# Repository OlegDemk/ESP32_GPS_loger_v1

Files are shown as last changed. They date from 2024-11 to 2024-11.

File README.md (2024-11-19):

GPS logger can log in GPS data every 5 seconds into Micro SD card. 

File can be downloaded over Wifi HTTP server or from MicroSD card. 

Log file can be upload on https://earth.google.com for see route. 

All information can be show on HTTP web server, if it turn on.

SMS command:

   command 	   ansvers
   
logON	- 	GPS log Start... Bat: 100%

logoff	- 	GPS log STOP Bat: 100%

point 	- 	49.XXXXXX, 23.XXXXXX Bat: 100%

restart - 	Restarting... Bat: 100%

WiFi commands ??????

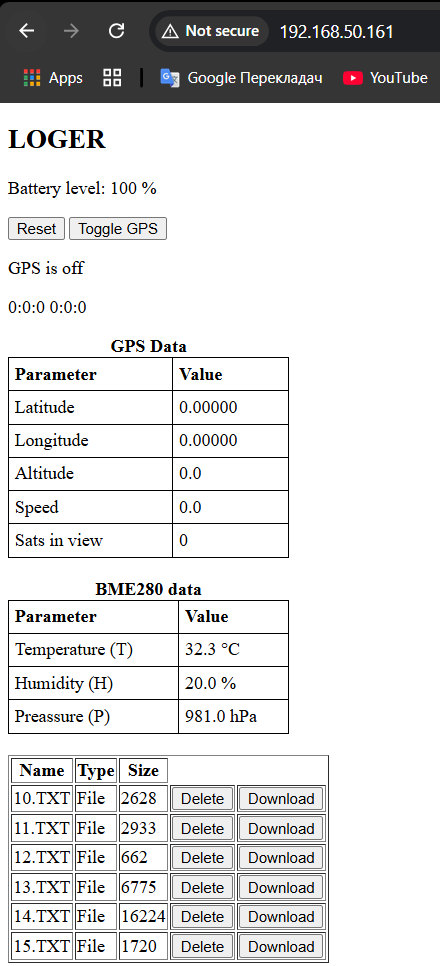
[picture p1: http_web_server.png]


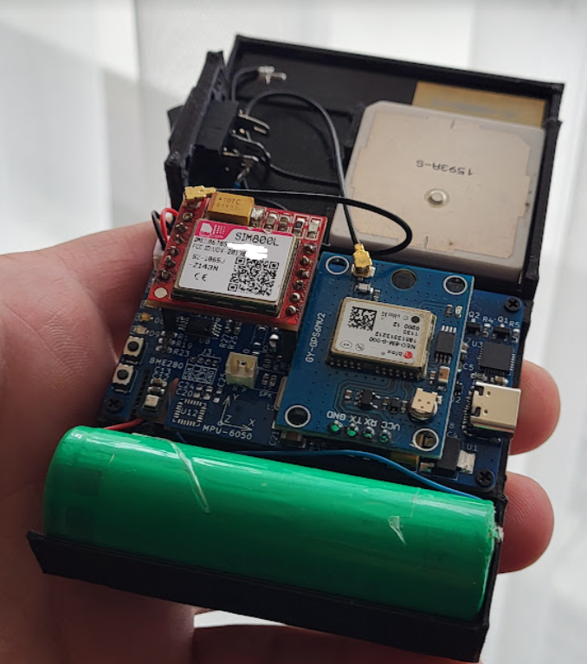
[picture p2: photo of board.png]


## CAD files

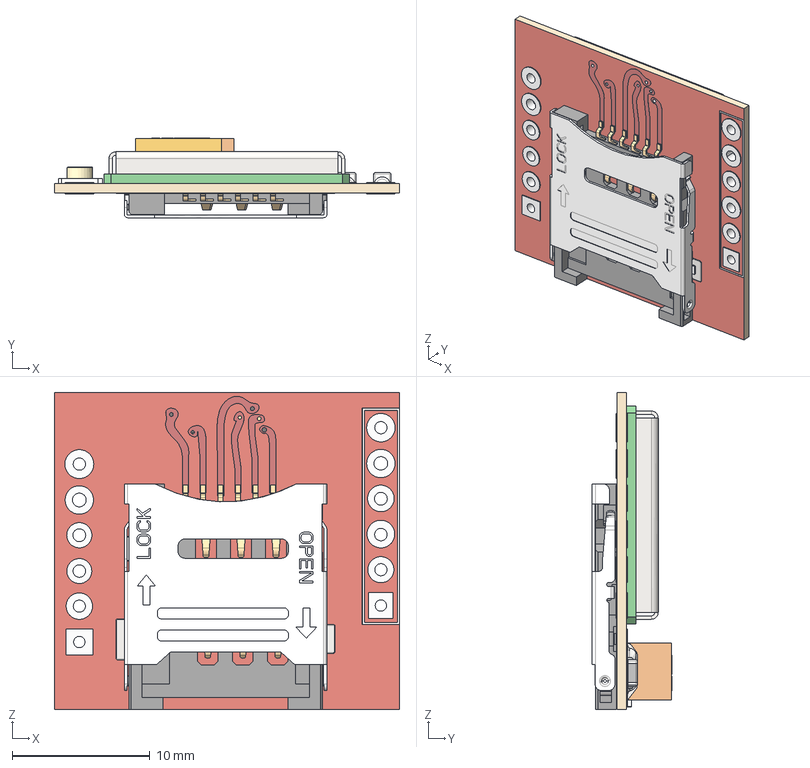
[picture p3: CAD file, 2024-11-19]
1. PCB/3d_models/SIM800L v10.step
25.0 x 5.77 x 23.0 mm
PCB
Cage
CH03-HB

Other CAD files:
3. Corpus 3D/GPS Loger.skp

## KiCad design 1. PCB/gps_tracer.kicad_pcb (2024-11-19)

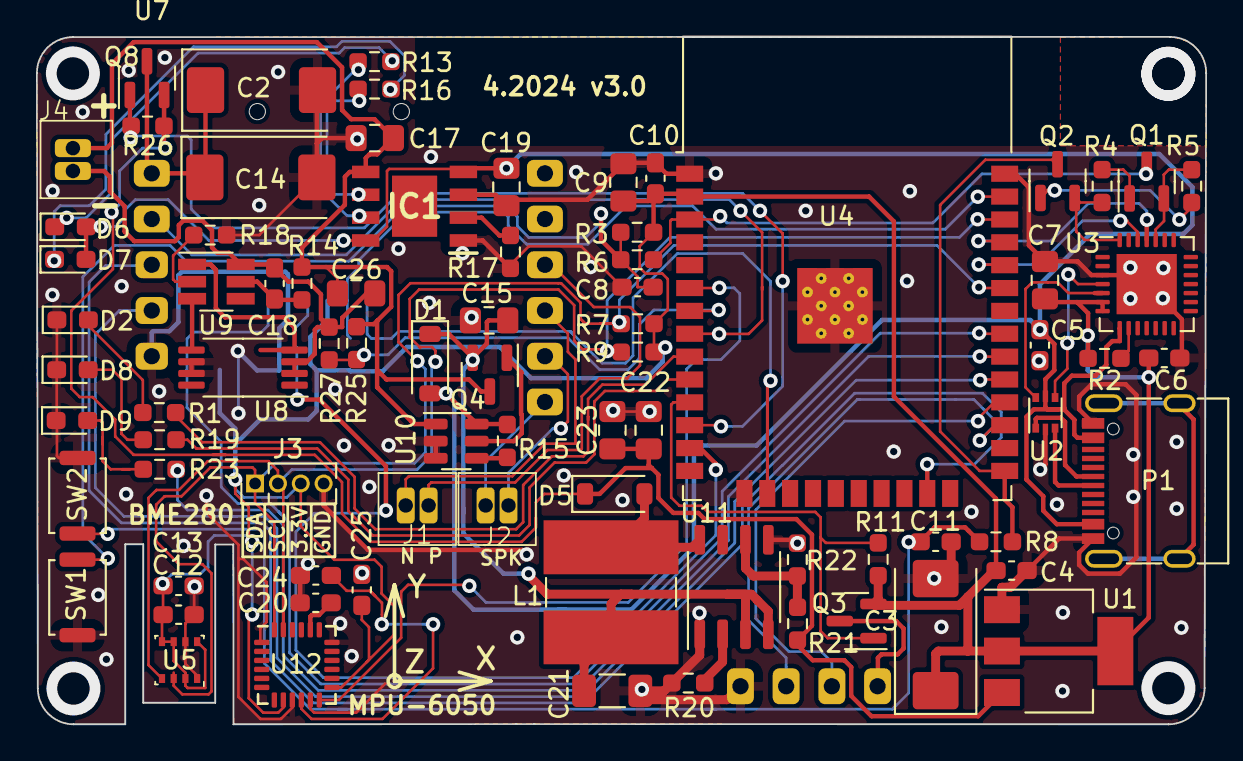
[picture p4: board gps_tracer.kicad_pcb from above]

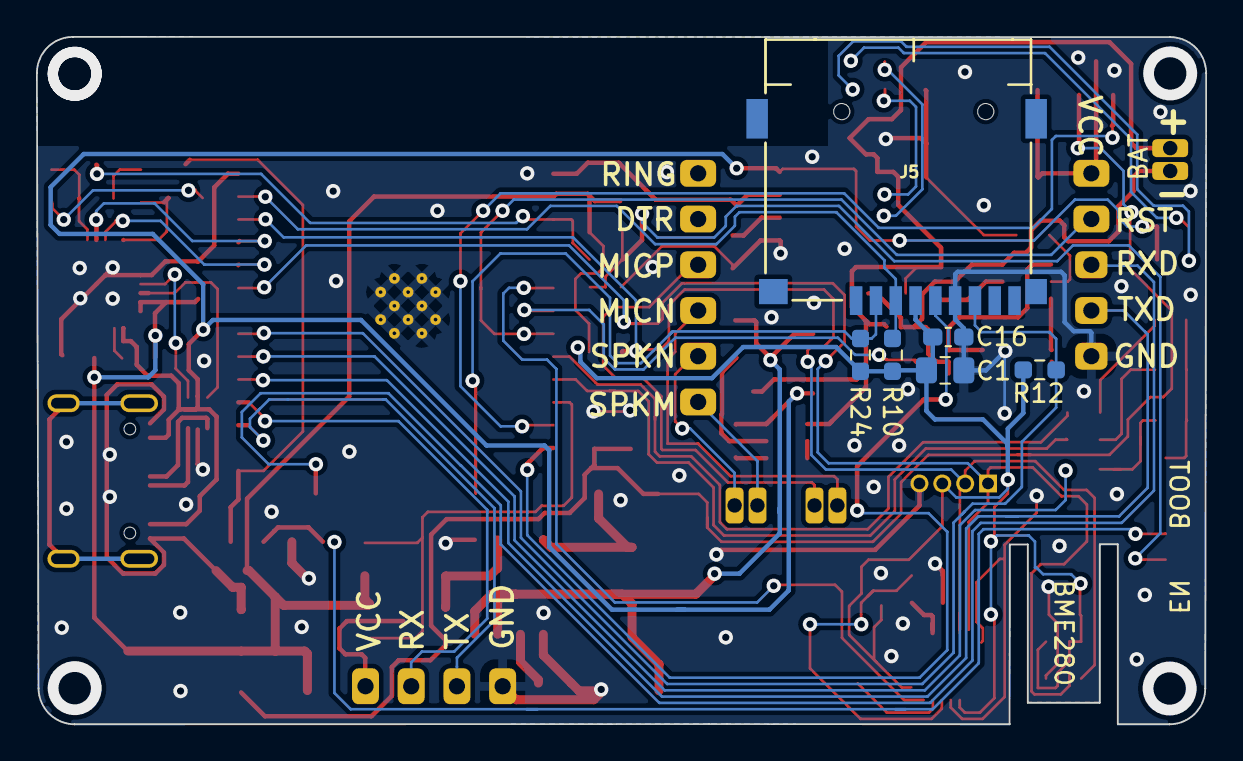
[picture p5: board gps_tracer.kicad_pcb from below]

Board: 2 copper layers, 65.0 x 38.2 mm, 88 parts (6 on the bottom side), 65 nets.

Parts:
AE1: Antenna; GPS_ANTENNA
C1, C9, C15, C22, C23, C26: 22u; C_0805_2012Metric_Pad1.18x1.45mm_HandSolder
C2, C3, C14: 470u; CP_EIA-7343-31_Kemet-D
C4, C5, C6, C8, C10, C11, C12, C13, C20, C24, C25: 100n; C_0603_1608Metric_Pad1.08x0.95mm_HandSolder
C7: 47u; C_0805_2012Metric_Pad1.18x1.45mm_HandSolder
C16, C18: 100nF; C_0603_1608Metric_Pad1.08x0.95mm_HandSolder
C17, C19: 16uF; C_0805_2012Metric_Pad1.18x1.45mm_HandSolder
C21: 100u; C_1206_3216Metric_Pad1.33x1.80mm_HandSolder
D1, D5: BAT48ZFILM; D_SOD-123
D2, D8, D9: LED; LED_0603_1608Metric_Pad1.05x0.95mm_HandSolder
D6: LED Charging red; LED_0603_1608Metric_Pad1.05x0.95mm_HandSolder
D7: LED Full blue; LED_0603_1608Metric_Pad1.05x0.95mm_HandSolder
IC1: TC4056A; SOIC127P600X175-9N
J1: Mic; JST 1.25
J2: SPK; JST 1.25
J3: I2C; PinHeader_1x04_P1.27mm_Vertical
J4: BATTERY; JST 1.25
J5: Micro_SD_Card; J_SD_Card-micro_socket_A (1)
L1: 3.3uH; L_Ferrocore_DLG-0703
P1: USB_C_Plug_USB2.0; USB_C_Receptacle_G-Switch_GT-USB-7010ASV
Q1, Q2: S8050; SOT-23
Q3, Q8: FDN358P; SOT-23
Q4: LTC4412; SOT-23
R1, R19, R23: 700; R_0603_1608Metric_Pad0.98x0.95mm_HandSolder
R2: 2k; R_0603_1608Metric_Pad0.98x0.95mm_HandSolder
R3, R4, R5, R10, R12, R22, R24: 10k; R_0603_1608Metric_Pad0.98x0.95mm_HandSolder
R6, R8: 470; R_0603_1608Metric_Pad0.98x0.95mm_HandSolder
R7, R9: 4.7k; R_0603_1608Metric_Pad0.98x0.95mm_HandSolder
R11, R26: 9k; R_0603_1608Metric_Pad0.98x0.95mm_HandSolder
R13, R16, R18: 1k; R_0603_1608Metric_Pad0.98x0.95mm_HandSolder
R14: 100; R_0603_1608Metric_Pad0.98x0.95mm_HandSolder
R15: 470k; R_0603_1608Metric_Pad0.98x0.95mm_HandSolder
R17: 1200; R_0603_1608Metric_Pad0.98x0.95mm_HandSolder
R20: 30k; R_0603_1608Metric_Pad0.98x0.95mm_HandSolder
R21: 73.2k; R_0603_1608Metric_Pad0.98x0.95mm_HandSolder
R25, R27: ????; R_0603_1608Metric_Pad0.98x0.95mm_HandSolder
SW1: EN; SW_Push_SPST_NO_Alps_SKRK
SW2: BOOT; SW_Push_SPST_NO_Alps_SKRK
U1: AMS1117-3.3; SOT-223-3_TabPin2
U2: USBLC6-2P6; SOT-666
U3: CP2102N-Axx-xQFN28; QFN-28-1EP_5x5mm_P0.5mm_EP3.35x3.35mm
U4: ESP32-WROOM-32
U5: BME280; Bosch_LGA-8_2.5x2.5mm_P0.65mm_ClockwisePinNumbering
U6: GY_GPS6MV2_module
U7: SIM800L-CORE
U8: FS8205A; TSSOP-8_4.4x3mm_P0.65mm
U9: DW01A; SOT-23-6_Handsoldering
U10: LTC4412xS6; TSOT-23-6
U11: FP6298; SOP-8_3.9x4.9mm_P1.27mm
U12: MPU-6050; InvenSense_QFN-24_4x4mm_P0.5mm

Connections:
+3.3V: C1.1, C3.1, C4.1, C6.1, C7.1, C9.1, C10.1, C12.1, C13.1, C16.1, C25.2, J3.3, J5.4 (VSS), Q3.2 (S), R2.1, R3.1, R7.1, R9.1, R10.2, R11.2, R12.2, R24.2, U1.2 (VO), U3.6 (VDD), U3.7 (VREGIN), U4.2 (VDD), U5.2 (CSB), U5.5 (SDO), U5.6 (VDDIO), U5.8 (VDD), U12.8 (VLOGIC), U12.13 (VDD)
+5V: C5.1, C19.1, D1.2 (A), D6.2 (A), D7.2 (A), IC1.4 (VCC), IC1.8 (CE), P1.A4 (VBUS), P1.A9 (VBUS), P1.B4 (VBUS), P1.B9 (VBUS), R15.1, U2.5 (VBUS), U3.8 (VBUS), U10.6 (SENSE)
BATTERY_VOLTAGE: R25.2, R27.1, U4.7 (IO35)
BLUE_LED: R1.1, U4.9 (IO33)
DTR: Q2.2 (E), R4.2, U3.28 (~DTR)
DTS: Q1.2 (E), R5.2, U3.24 (~RTS)
EN: Q1.3 (C), R6.1, U4.3 (EN)
GND: C1.2, C2.2, C3.2, C4.2, C5.2, C6.2, C7.2, C8.2, C9.2, C10.2, C11.2, C12.2, C13.2, C14.2, C15.2, C16.2, C17.2, C19.2, C20.1, C21.2, C22.2, C23.2, C24.1, C25.1, D2.1 (K), D8.1 (K), D9.1 (K), IC1.1 (TEMP), IC1.3 (GND), J3.4, J5.6 (VDD), P1.A1 (GND), P1.A12 (GND), P1.B1 (GND), P1.B12 (GND), R17.1, R18.1, R20.1, R22.1, SW1.1, SW2.2, U1.1 (GND), U2.2 (GND), U3.3 (GND), U3.29 (GND), U4.1 (GND), U4.15 (GND), U4.38 (GND), U4.39 (GND), U5.1 (GND), U5.7 (GND), U6.4 (GND), U7.5 (GND), U8.6 (S2), U8.7 (S2), U10.2 (GND), U10.3 (CTL), U11.1 (PGND), U11.5 (GND), U12.1 (CLKIN), U12.9 (AD0), U12.11 (FSYNC), U12.18 (GND)
GPS_RX: U4.28 (IO17), U6.2 (RX)
GPS_TX: U4.27 (IO16), U6.3 (TX)
GREEN_LED: R19.1, U4.10 (IO25)
GSM_POWER_SOURSE: C22.1, C23.1, D5.1 (K), Q8.2 (S), R21.2, R26.2, U1.3 (VI)
IO0: Q2.3 (C), R8.2, U4.25 (IO0)
MICROSD_CLK: J5.5 (CLK), U4.13 (IO14)
MICROSD_CS: J5.2 (DAT1), R24.1, U4.16 (IO13)
MICROSD_MISO: J5.7 (CMD), R12.1, U4.31 (IO19)
MICROSD_MOSI: J5.3 (DAT0), R10.1, U4.37 (IO23)
MPU5060_INT: U4.6 (IO34), U12.12 (INT)
unnamed: C8.1, R3.2, R6.2, SW1.2
unnamed: C11.1, R8.1, SW2.1
unnamed: C15.1, C21.1, D1.1 (K), L1.1, Q4.2 (S), U11.3 (Vcc), U11.4 (EN)
unnamed: D2.2 (A), R1.2
unnamed: D5.2 (A), L1.2, U11.8 (LX)
unnamed: D6.1 (K), R13.2
unnamed: D7.1 (K), R16.2
unnamed: D8.2 (A), R19.2
unnamed: D9.2 (A), R23.2
unnamed: C17.1, C26.1, IC1.5 (BAT), J4.2, Q4.3 (D), R14.1, R25.1, U10.1 (VIN)
unnamed: IC1.7 (CHRG), R13.1
unnamed: IC1.2 (PROG), R17.2
unnamed: IC1.6 (STDBY), R16.1
unnamed: J1.1, U7.8 (MICN)
unnamed: J1.2, U7.9 (MICP)
unnamed: J2.1, U7.6 (SPKM)
unnamed: J2.2, U7.7 (SPKN)
unnamed: C18.2, C26.2, J4.1, R27.2, U8.2 (S1), U8.3 (S1), U9.6 (GND)
unnamed: P1.A6 (D+), U2.3 (I/O2)
unnamed: P1.A7 (D-), U2.1 (I/O1)
unnamed: Q1.1 (B), R4.1
unnamed: Q2.1 (B), R5.1
unnamed: Q3.3 (D), U6.1 (VCC)
unnamed: Q4.1 (G), U10.5 (GATE)
unnamed: C2.1, C14.1, Q8.3 (D), U7.1 (VCC)
unnamed: U2.4 (I/O2), U3.4 (D+)
unnamed: U2.6 (I/O1), U3.5 (D-)
unnamed: R2.2, U3.9 (~RST)
unnamed: R18.2, U9.2 (CS)
unnamed: C18.1, R14.2, U9.5 (VCC)
unnamed: R15.2, U10.4 (STAT)
unnamed: R21.1, R22.2, U11.6 (FB)
unnamed: R20.2, U11.2 (OC)
unnamed: C20.2, U12.20 (CPOUT)
unnamed: C24.2, U12.10 (REGOUT)
OC: U8.5 (G2), U9.3 (OC)
OD: U8.4 (G1), U9.1 (OD)
POWER_OF_GPS: Q3.1 (G), R11.1, U4.11 (IO26)
POWER_OF_GSM: Q8.1 (G), R26.1, U4.12 (IO27)
RED_LED: R23.1, U4.30 (IO18)
RST_GSM: U4.8 (IO32), U7.2 (RST)
RXD: U3.26 (TXD), U4.34 (RXD0/IO3)
RXD_GSM: U4.23 (IO15), U7.3 (RXD)
SCL: J3.2, R9.2, U4.36 (IO22), U5.4 (SCK), U12.23 (SCL)
SDA: J3.1, R7.2, U4.33 (IO21), U5.3 (SDI), U12.24 (SDA)
TXD: U3.25 (RXD), U4.35 (TXD0/IO1)
TXD_GSM: U4.29 (IO5), U7.4 (TXD)

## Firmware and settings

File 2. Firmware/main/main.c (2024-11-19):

#include "main.h"


uint8_t raad_barrety_level(void);


// Task handlers
TaskHandle_t task_bme280_handlr;
TaskHandle_t task_led_blink_handler;
TaskHandle_t task_resurse_monitor_handlr;
TaskHandle_t task_log_data_into_file_handlr;
TaskHandle_t task_gsm_handler;
TaskHandle_t task_get_gps_data_one_time_handler;
TaskHandle_t task_battery_data_handle;

// Queues
QueueHandle_t gps_data_log_queue = NULL;

#define QUEUE_LENGHT_BME280 1
QueueHandle_t bme280_queue = NULL;

#define QUEUE_LENGHT_GPS 1
QueueHandle_t GPS_queue = NULL;

#define QUEUE_LENGHT_BATTERY 1
QueueHandle_t battery_queue = NULL;


// ------------------------------------------------------------------------------------------------------------------
void task_resurse_monitor(void *ignore)
{
	while(1)
	{
        char status[1024] = {0,};

		// Shows: name of tasks, status, priority, free stack size and task number on each tasks
		vTaskList(status);
		ESP_LOGI("\033[1;36mTaskList", "\n%s\033[1;36m", status);

        // Shows: spend time cheduller on each tasks
        memset(status, 0, sizeof(status));
        vTaskGetRunTimeStats(status);
        ESP_LOGI("\033[1;36mRunTimeStats", "\n%s\033[1;36m", status);

		vTaskDelay(15000/portTICK_PERIOD_MS);		
	}
}
// ------------------------------------------------------------------------------------------------------------------
void task_blink(void *ignore)				// For debug
{
	while(1)
	{
		gpio_set_level(CONFIG_BLUE_GPIO, 1);
		vTaskDelay(50 / portTICK_PERIOD_MS);
		gpio_set_level(CONFIG_BLUE_GPIO, 0);
		vTaskDelay(950 / portTICK_PERIOD_MS);
	}
}
// ------------------------------------------------------------------------------------------------------------------
void task_bme280(void *ignore)
{
	static const char *TAG_BME280 = "BME280";

	bme280_thp_t bme280_thp_queue;

	i2c_master_init_BME280();

	struct bme280_t bme280 = {
		.bus_write = BME280_I2C_bus_write,
		.bus_read = BME280_I2C_bus_read,
		.dev_addr = BME280_I2C_ADDRESS2,
		.delay_msec = BME280_delay_msek
	};

	s32 com_rslt;
	s32 v_uncomp_pressure_s32;
	s32 v_uncomp_temperature_s32;
	s32 v_uncomp_humidity_s32;

	com_rslt = bme280_init(&bme280);

	com_rslt += bme280_set_oversamp_pressure(BME280_OVERSAMP_16X);
	com_rslt += bme280_set_oversamp_temperature(BME280_OVERSAMP_2X);
	com_rslt += bme280_set_oversamp_humidity(BME280_OVERSAMP_1X);
	com_rslt += bme280_set_standby_durn(BME280_STANDBY_TIME_1_MS);
	com_rslt += bme280_set_filter(BME280_FILTER_COEFF_16);

	com_rslt += bme280_set_power_mode(BME280_NORMAL_MODE);

	if (com_rslt == SUCCESS)
	{
		while(true)
		{
			com_rslt = bme280_read_uncomp_pressure_temperature_humidity(
				&v_uncomp_pressure_s32, &v_uncomp_temperature_s32, &v_uncomp_humidity_s32);

			if (com_rslt == SUCCESS)
			{
				double t = bme280_compensate_temperature_double(v_uncomp_temperature_s32);
				double p = bme280_compensate_pressure_double(v_uncomp_pressure_s32)/100;
				double h = bme280_compensate_humidity_double(v_uncomp_humidity_s32);

				bme280_thp_queue.temperature = t;
				bme280_thp_queue.humidity = h;
				bme280_thp_queue.preassure = p;

				BaseType_t result = xQueueSend(bme280_queue, (void*)&bme280_thp_queue, pdMS_TO_TICKS(100));
				if(result == pdPASS)
				{
					ESP_LOGI(TAG_BME280, "Send data: T:%.1f, H:%.1f, P:%.1f", bme280_thp_queue.temperature, bme280_thp_queue.humidity, bme280_thp_queue.preassure);
				}
				else if(result == errQUEUE_FULL)
				{
					ESP_LOGE(TAG_BME280, "The queue is full");		 
				}
				else
				{
					ESP_LOGE(TAG_BME280, "Failed send BME280 data");
				}


				ESP_LOGI(TAG_BME280, "%.2f degC / %.3f hPa / %.3f %%", t, p, h);
			}
			else
			{
				ESP_LOGE(TAG_BME280, "measure error. code: %d", com_rslt);
			}

			vTaskDelay(1000/portTICK_PERIOD_MS);
		}
	}
	else
	{
		ESP_LOGE(TAG_BME280, "init or setting error. code: %d", com_rslt);
	}
	vTaskDelete(NULL);
}
// -------------------------------------------------------------------------------------------------------------------
void send_sms_message_plus_battery_level(char *message)
{
	//	Add battery level to sms
	char buff_sms_str[35] = {0};
	uint8_t battery_level = raad_barrety_level();

	snprintf(buff_sms_str, sizeof(buff_sms_str), "%s Bat: %d%%", message, battery_level);
	send_sms(CONFIG_MY_MOBILE_NUMBER, buff_sms_str);
}
// -------------------------------------------------------------------------------------------------------------------

bool init_gps_status_flag = false;
bool gps_log_working_flag = false;

void task_log_data_into_file(void *ignore)
{
	static const char *LOG_TAG = "LOG GPS DATA";
	
	uint8_t log_data_save_period = 5;				// Period of lging data into Micro CD.
	int gps_data_incoming_counter = 1;			
	int gps_point_counter = 0;						// Point counter, for save into file.
	bool init = true;								// For create new file(first time) or add new GPS data to old file.
	
	gps_data_gps_t gps_data;
	BaseType_t qStatus = false;
	
	const char* base_path = "/data";
	
	// Get name for new file (using flash memory)
	char name[20] = {0,};
	get_file_name(&name);						   // некоректно вертає назву файлу <<<<<<<<<<<<<<<<<<<<<<<<<<<<<<<<<<<<
	
	if(init_gps_status_flag == false)														// If GPS module was OFF
	{
		turn_on_gps();
		init_gps_status_flag = true;
	}
	
	#if SMS_FITBACK == ON	
		send_sms_message_plus_battery_level("GPS log Start...");							//	Add battery level to sms
	#endif
	
	while(1)
	{
		qStatus = xQueueReceive(gps_data_log_queue, &gps_data, 1000/portTICK_PERIOD_MS);	// Receive GPS dsta from GPS
		if(qStatus == pdPASS)
		{
			show_gps_data(&gps_data);
			gps_signal_led_indication(&gps_data);
			send_data_to_client(&gps_data);													

			if(gps_data_incoming_counter == log_data_save_period)							// SaveGPS data periodically
			{
				if(init == true)															//	If save data first time
				{
					log_data1(base_path, name, &gps_data);
					init = false;
				}
				else
				{
					log_data2(base_path, name, &gps_data, gps_point_counter++);
				}
			}
			gps_data_incoming_counter++;
			if(gps_data_incoming_counter > log_data_save_period)
			{
				gps_data_incoming_counter = 0;
			}
		}
		vTaskDelay(500/portTICK_PERIOD_MS);
	}
}
// ----------------------------------------------------------------------------------------------
void task_get_gps_data_one_time(void* ignode)
{
	static const char *GSM_TAG = "GPS";
	
	gps_data_gps_t gps_data;
	BaseType_t qStatus = false;
	int status = 0;
	
	#if SMS_FITBACK == ON
		send_sms_message_plus_battery_level("One point GPS START...");
	#endif
	
	ESP_LOGI(GSM_TAG, "GET ONE SHOT GPS DATA...");
	
	vTaskDelay(10000 / portTICK_PERIOD_MS);													// It delay need betvean two SMS
	
	if(init_gps_status_flag == false)														// If GPS module in OFF state
	{
		turn_on_gps(); 
		init_gps_status_flag = true;
	}
	
	while(1)
	{
		qStatus = xQueueReceive(gps_data_log_queue, &gps_data, 1000/portTICK_PERIOD_MS);	// Receive GPS dsta from GPS
		if(qStatus == pdPASS)
		{
			gps_signal_led_indication(&gps_data);
			show_gps_data(&gps_data);
			
			int status = check_gps_data_valid(&gps_data); 
			if(status == 1)																	// if GPS data valid 
			{
				ESP_LOGI(GSM_TAG, "GSM data valid ");
				char buff[50] = {0,};
				
				sprintf(buff, "%05f, %05f", gps_data.latitude, gps_data.longitude);
				//send sms with GPS data
				#if SMS_FITBACK == ON
					send_sms_message_plus_battery_level(buff);
				#endif
		
				vTaskDelay(1000 / portTICK_PERIOD_MS);

				// If GPS_log mode is in OFF mode, then GPS can be turn OFF
				if(gps_log_working_flag == false)
				{
					ESP_LOGI(GSM_TAG, "TURN OFF GPS MODULE");   
					turn_off_gps();
					init_gps_status_flag = false;
				}
				gpio_set_level(CONFIG_GREEN_GPIO, 0);
				
				ESP_LOGI(GSM_TAG, "Delete one shot GPS log task");
				vTaskDelete(NULL);	
			}
		}
	}
}
// ----------------------------------------------------------------------------------------------
void task_gsm(void *ignore)
{
	static const char *GSM_TAG = "GSM";
	int buf_size = 1024;

	ESP_LOGI(GSM_TAG ,"Primary mobile number: %s", CONFIG_MY_MOBILE_NUMBER);
	
	vTaskDelay(1000 / portTICK_PERIOD_MS);

	gsm(ON);																					// turn on GSM module by defoult
	init_uart_for_gsm();
	vTaskDelay(12000 / portTICK_PERIOD_MS);														// Delay for load GSM module
	
	init_sim800l();

	while(1)
	{
		uint8_t data[buf_size];
		
		int length = uart_read_bytes(UART_NUM_1, data, buf_size, 1000/portTICK_PERIOD_MS);			// Waiting data from GSM module
		if(length > 0)
		{
			data[length] = '\0';
			ESP_LOGI(GSM_TAG, "New message from GSM: %s", data);
			
			if(strstr((char*)data, "RING") != NULL)													// If incoming call detected
			{
				ESP_LOGI(GSM_TAG, "Incoming call");
				
				// Define incoming phone namber. If it my number answer call
				send_at_command("AT+CLCC\r\n");					
				vTaskDelay(1000 / portTICK_PERIOD_MS);
				
				uint8_t response[buf_size];
                read_gsm_response(response, buf_size);
				
				if (strstr((char*)response, CONFIG_MY_MOBILE_NUMBER) != NULL)
                {
                    ESP_LOGI(GSM_TAG, "Authorized number calling: %s", CONFIG_MY_MOBILE_NUMBER);
                    answer_call(); 																	// Pick up the phone
                }
                else
                {
                    ESP_LOGI(GSM_TAG, "Unauthorized number calling. Ignoring call.");
                    send_at_command("ATH\r\n");  													// Hung up the phone
                }	
			}
			else if(strstr((char*)data, "+CMT") != NULL)											// If incoming SMS detected
			{
				ESP_LOGI(GSM_TAG, "SMS received, checking the content...");
				
				// Check if it's from the authorized number
    			if (strstr((char*)data, CONFIG_MY_MOBILE_NUMBER) != NULL)
    			{
					process_sms((char*)data);
				}
				else
				{
					ESP_LOGI(GSM_TAG, "SMS from unauthorized number. Ignoring.");
				}
			}
		}
	}
}
// ------------------------------------------------------------------------------------------

void restart_all_esp32(void)
{
	turn_off_gps_module();
	#if SMS_FITBACK == ON
		send_sms_message_plus_battery_level("Restarting...");
	#endif
	
	esp_restart();
}
// ------------------------------------------------------------------------------------------




// ------------------------------------------------------------------------------------------------------------
void task_battery_data(void *ignore)
{
	const static char *TAG_BATTERY = "BATTERY TASK";

	battery_t batterty;
	batterty.battery_level = 0;

	while(1)
	{
		batterty.battery_level = raad_barrety_level();  

		BaseType_t result = xQueueSend(battery_queue, (void*)&batterty, pdMS_TO_TICKS(100));
		if(result == pdPASS)
		{
			ESP_LOGI(TAG_BATTERY, "Send battery data: %d", batterty.battery_level);
		}
		else if(result == errQUEUE_FULL)
		{
			ESP_LOGE(TAG_BATTERY, "The queue is full");		
		}
		else
		{
			ESP_LOGE(TAG_BATTERY, "Failed send battery data");
		}
		
		vTaskDelay(1000 / portTICK_PERIOD_MS);
	}
}
// ----------------------------------------------------------------------------------------------------------------------------------------
void app_main(void)
{
	bme280_queue = xQueueCreate(QUEUE_LENGHT_BME280, sizeof(bme280_thp_t)); 
	if(bme280_queue == NULL)
	{
		ESP_LOGE("CREATE QUEUE" ,"Failed create bme280 queue");
		return;
	}
	
	GPS_queue = xQueueCreate(QUEUE_LENGHT_GPS, sizeof(gps_data_gps_t)); 
	if(GPS_queue == NULL)
	{
		ESP_LOGE("CREATE QUEUE" ,"Failed create GPS_queue queue");
		return;
	}
	
	battery_queue = xQueueCreate(QUEUE_LENGHT_BATTERY, sizeof(battery_t)); 
	if(battery_queue == NULL)
	{
		ESP_LOGE("CREATE QUEUE" ,"Failed create GPS_queue queue");
		return;
	}

    init_output_gpio();
	RGB_LEDs_blink(5, 25);

	const char* base_path = "/data";
    ESP_ERROR_CHECK(example_mount_storage(base_path));		

	init_http_server();

	xTaskCreate(task_battery_data, "task_battery_data", 4096, NULL, configMAX_PRIORITIES - 2, &task_battery_data_handle);
    xTaskCreate(task_blink, "task_blink", 1024, NULL, configMAX_PRIORITIES - 3, &task_led_blink_handler);
    xTaskCreate(task_bme280, "task_bme280", 4096, NULL, configMAX_PRIORITIES - 2, &task_bme280_handlr);
    xTaskCreate(task_resurse_monitor, "task_resurse_monitor", 4096, NULL, configMAX_PRIORITIES - 3, &task_resurse_monitor_handlr);

	vTaskDelay(2000 / portTICK_PERIOD_MS);
	xTaskCreate(task_gsm, "task_gsm", 4096, NULL, configMAX_PRIORITIES - 1, &task_gsm_handler);

	

	// Віддибажити старт і стоп вебсервера
	// for(int i = 0; i <= 10; i++)
	// {
	// 	ESP_LOGI("HTTP WEB SERVER" ,"START <<<<<<<<<<<<<<<<<<<<<<<<<<<<<<<<<<<<<<<<<<<<<<<<<<<<<<");
	// 	init_http_server();
	// 	vTaskDelay(15000 / portTICK_PERIOD_MS);

	// 	ESP_LOGI("HTTP WEB SERVER" ,"STOP <<<<<<<<<<<<<<<<<<<<<<<<<<<<<<<<<<<<<<<<<<<<<<<<<<<<<<");
	// 	stop_http_server();
	// 	vTaskDelay(10000 / portTICK_PERIOD_MS);
	// }






/*
	CURRENT:
		2. Залити проект з VS Code і новою версією плати на ГітХАБ
		1. Запускати HTTP server з SMS командою.

	BUGS:


	TASKS:
		4. Зробити реалізацію кнопки старту і стопу запису GPS даних. (кнопка має знати стан GPS логера, чи він включений чи ні) Додати кнопки LogON logOFF і point
		3. Добавити можливість налаштування підключення до вибраного AP.
		
		
		3. При скачуванні файла додеється знак "_" перед назвою файла.
		7. Логування даних в консоль. Порифакторити всі LOG_TAGs 
		10. Рефакторити код в main.c, позабирати лишні функції в різні папки і файли
		2. Пофіксити Config файл.
		1. Оптимізувати енергоспоживання дівайсу
		5. Замінити task_blink з задачі на наймер

	DONE:
		2. Некоректно відображаються GPS діні в таблиці на сторінці.
		1. Відсилати реальні GSM а не фейкові.
		3. Під час команди logON дані не записуються в файл --------- SPI FLASH WRITE DATA: File can't create log file: writing data  -------- E (588183) log_data2 FUNCTION: : File can't be write !	(повторно монтую карту памяті, в фіункції логування, якщо вона не змонтована корректно)
		6. Зробити реальну передачу стану заряду акумулятора. (потім реалізувати її як функцію)
		8. Не відображати системні папки і файли в таблиці HTTP сервера.
		1. ПРи включеному сервері рандомно віирубається логування даних в файл. При цьому що файл займає в районі 50000 байт. 
		9. Додавати у відповідь на будь яку командою SMS стан заряду дівайсу. 
		1. Додавати до кожної точки геолокації Саму геолокацію, швидкість і час, які взяти з даних GPS.	
		1. ПРи включеному сервері рандомно віирубається логування даних в файл.	При цьому що файл займає в районі 50000 байт. 
		1 .БАГ нормально не всі ЛОГИ логує в один файл і кожного разу дописує в нього а не створює новий !₴!!!!
			E (163603) sdmmc_cmd: sdmmc_read_sectors_dma: sdmmc_send_cmd returned 0x108
			E (163603) diskio_sdmmc: sdmmc_read_blocks failed (0x108)
		2. Записувати мій номер в конфізі.

*/

}
// ------------------------------------------------------------------------------------------------------------------
